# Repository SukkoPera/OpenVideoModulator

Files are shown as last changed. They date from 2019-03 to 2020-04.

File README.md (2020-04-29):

# OpenVideoModulator
OpenVideoModulator is an Open Hardware adapter that converts an RGB video signal to Composite and S-Video.

Board

## Summary
OpenVideoModulator is an Open Hardware implementation of [a small circuit found on the Amstrad CPC Wiki](http://www.cpcwiki.eu/index.php/RGB_SVideo) that is able to produce a composite video signal from separate red, green and blue color component signals (plus sync). Since it uses the AD724 encoder, it is also able to produce an S-Video (Y/C) signal and it supports both the PAL and NTSC standards.

It has a compact form factor, a low component count and it only requires a +5V power supply. This makes it useful with old computers that do not have a native composite or S-Video output, like the Amstrad CPC or the Commodore Amiga 500 (which actually has a composite output but it's only black & white). It also tries to maintain the smallest possible form factor, which might allow for an internal installation.

## Assembly and Usage
First of all you need to choose whether you want PAL or NTSC output. The board is preconfigured for PAL, if you need NTSC you will need to cut the link between pads 1-2 on the top of the board and solder 2-3 together. The crystal frequency also depends on your choice: use 4.433619 MHz for PAL or 3.579545 MHz for NTSC.

Solder the AD724 chip first, then all surface-mount components. Finally complete the board with the through-hole connectors and crystal.

One of C6 and C7 should be enough. I use a 100uF on C6 but that is probably overkill. Play with them if your output video signal is unstable.

The Composite/S-Video connector can be found from many Chinese sellers under the name *AV-MDC-401*. I chose this one as it was perfect for my needs, but the board should be easy to adapt to different connectors.

Usage should be straightforward: just provide power (make sure to match the polarity!) and video signals to the board, then get your output from the other side. Note that the *sync* input requires a *composite sync* signal.

## License
The OpenVideoModulator documentation, including the design itself, is copyright &copy; SukkoPera 2019-2020.

OpenVideoModulator is Open Hardware licensed under the [CERN OHL v. 1.2](http://ohwr.org/cernohl).

You may redistribute and modify this documentation under the terms of the CERN OHL v.1.2. This documentation is distributed *as is* and WITHOUT ANY EXPRESS OR IMPLIED WARRANTIES whatsoever with respect to its functionality, operability or use, including, without limitation, any implied warranties OF MERCHANTABILITY, SATISFACTORY QUALITY, FITNESS FOR A PARTICULAR PURPOSE or infringement. We expressly disclaim any liability whatsoever for any direct, indirect, consequential, incidental or special damages, including, without limitation, lost revenues, lost profits, losses resulting from business interruption or loss of data, regardless of the form of action or legal theory under which the liability may be asserted, even if advised of the possibility or likelihood of such damages.

A copy of the full license is included in file [LICENSE.pdf](LICENSE.pdf), please refer to it for applicable conditions. In order to properly deal with its terms, please see file [LICENSE_HOWTO.pdf](LICENSE_HOWTO.pdf).

The contact points for information about manufactured Products (see section 4.2) are listed in file [PRODUCT.md](PRODUCT.md).

Any modifications made by Licensees (see section 3.4.b) shall be recorded in file [CHANGES.md](CHANGES.md).

The Documentation Location of the original project is https://github.com/SukkoPera/OpenVideoModulator/.

## Support the Project
Since the project is open you are free to get the PCBs made by your preferred manufacturer, however in case you want to support the development, you can order them from PCBWay through this link:

PCB from PCBWay (https://www.pcbway.com/project/shareproject/OpenVideoModulator_V1.html)

You get my gratitude and cheap, professionally-made and good quality PCBs, I get some credit that will help with this and [other projects](https://www.pcbway.com/project/member/shareproject/?bmbid=41100). You won't even have to worry about the various PCB options, it's all pre-configured for you!

Also, if you still have to register to that site, [you can use this link](https://www.pcbway.com/setinvite.aspx?inviteid=41100) to get some bonus initial credit (and yield me some more).

Again, if you want to use another manufacturer, feel free to, don't feel obligated :). But then you can buy me a coffee if you want:

<a href='https://ko-fi.com/L3L0U18L' target='_blank'>Buy Me a Coffee at ko-fi.com</a>

## Get Help
If you need help or have questions, you can join [the official Telegram group](https://t.me/joinchat/HUHdWBC9J9JnYIrvTYfZmg).

## Thanks
- CPC Wiki for the original circuit.

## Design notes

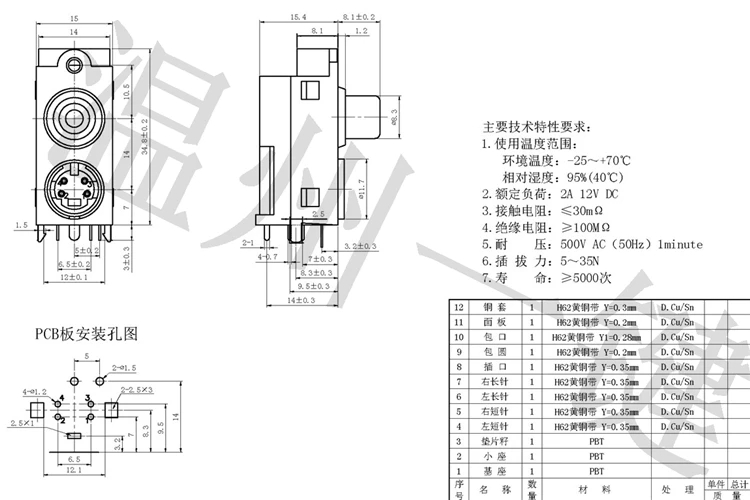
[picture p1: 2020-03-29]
doc/AV-MDC-401.jpg

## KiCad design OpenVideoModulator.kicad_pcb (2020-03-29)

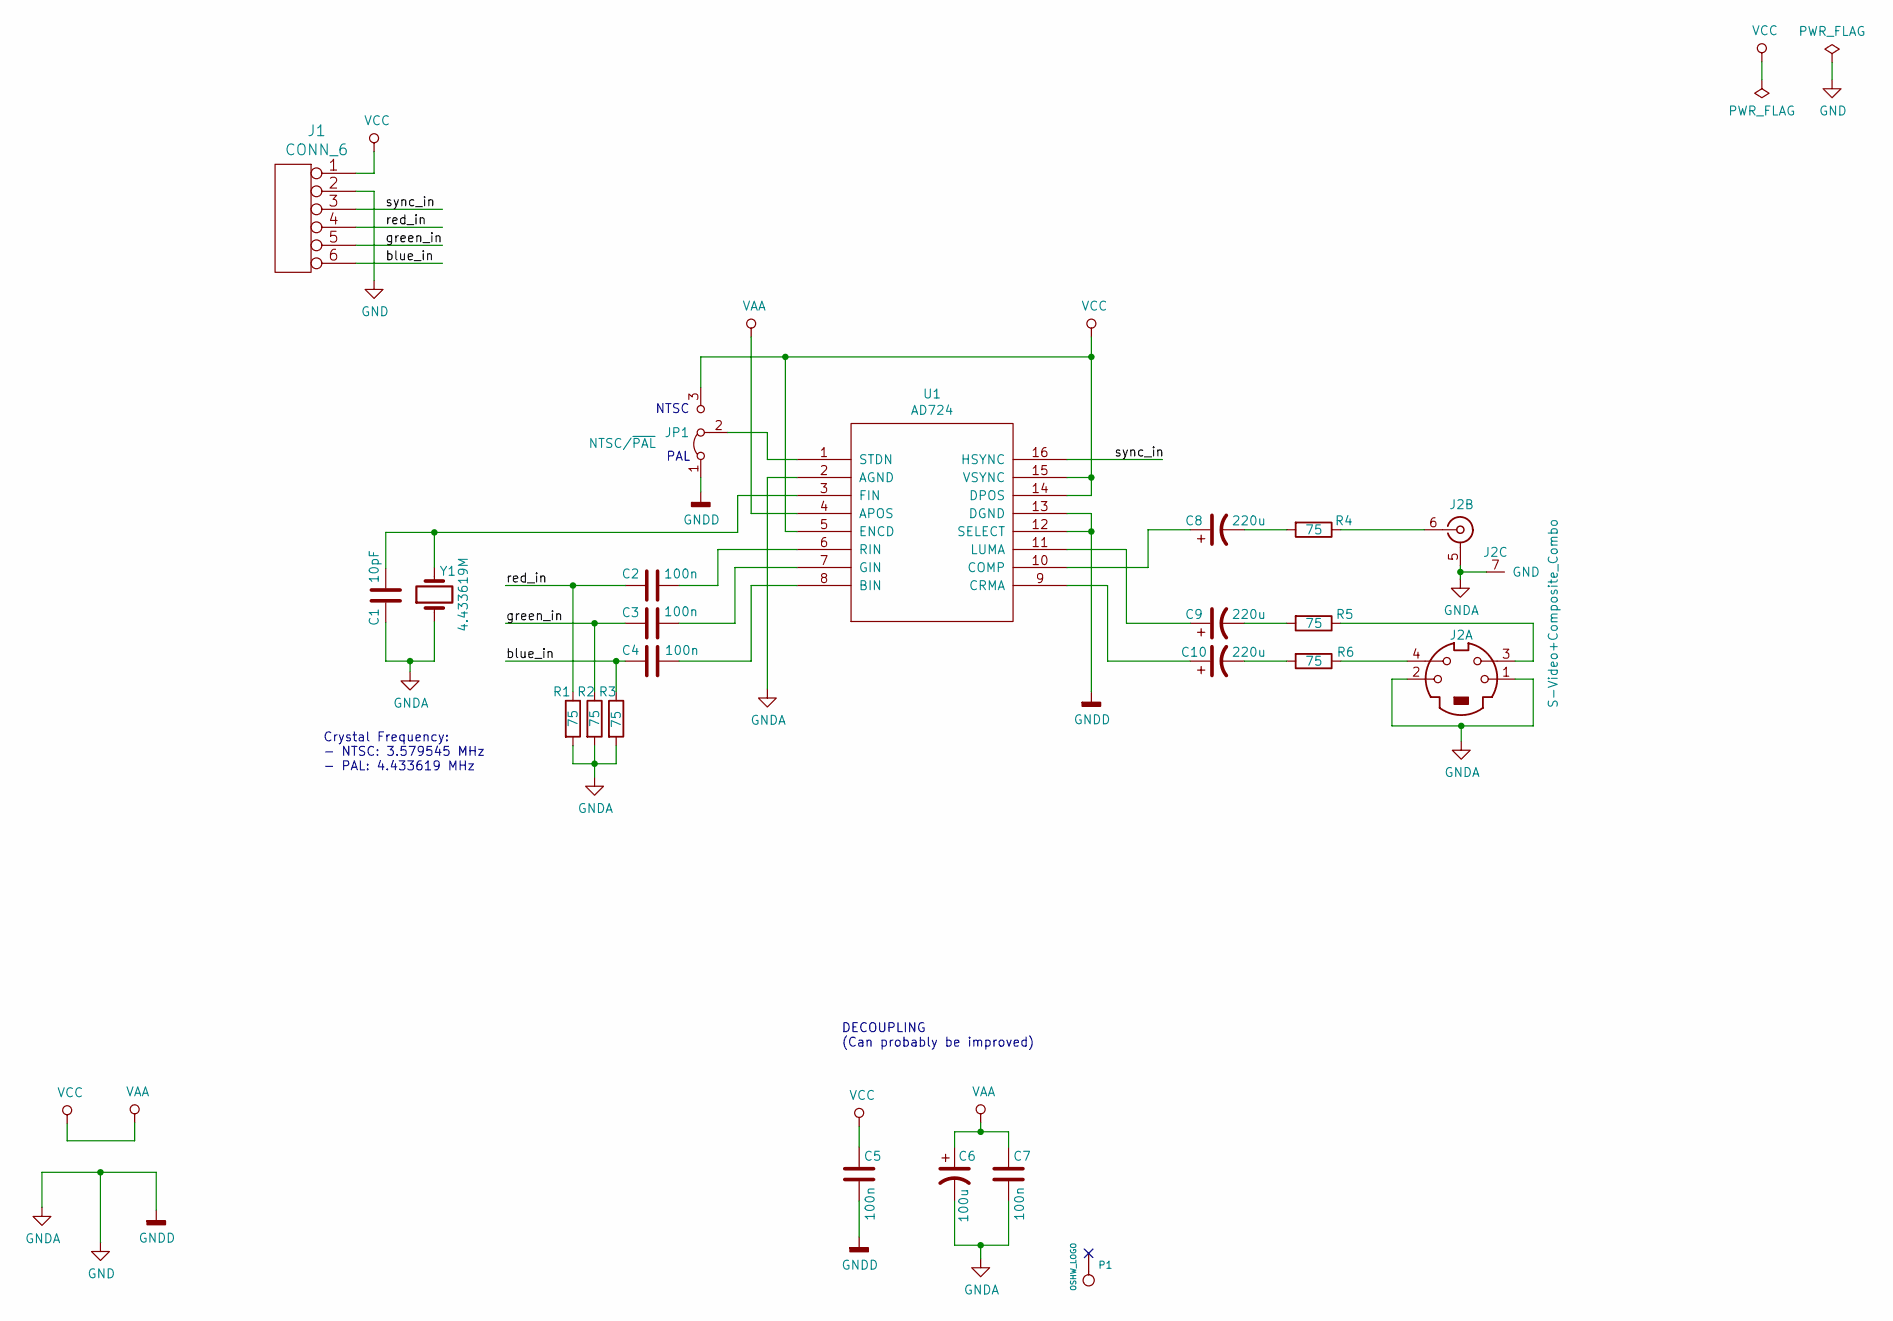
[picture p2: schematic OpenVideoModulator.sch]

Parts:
C1: 10pF; C_0805_2012Metric_Pad1.15x1.40mm_HandSolder
C2, C3, C4, C5: 100n; C_0805_2012Metric_Pad1.15x1.40mm_HandSolder
C6: 100u; CP_Elec_6.3x5.8
C7: 100n; C_1206_3216Metric_Pad1.42x1.75mm_HandSolder
C8, C9, C10: 220u; CP_Radial_D6.3mm_P2.50mm
J1: CONN_6; PinHeader_1x06_P2.54mm_Vertical
J2: S-Video+Composite_Combo; AV-MDC-401
JP1: NTSC/~PAL; SolderJumper-3_P1.3mm_Bridged12_RoundedPad1.0x1.5mm
P1: OSHW_LOGO; OSHW-Logo2_7.3x6mm_Copper
R1, R2, R3, R4, R5, R6: 75; R_0805_2012Metric_Pad1.15x1.40mm_HandSolder
U1: AD724; SOIC-16W_7.5x10.3mm_P1.27mm
Y1: 4.433619M; Crystal_HC49-4H_Vertical

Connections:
/blue_in: C4.2, J1.6, R3.1
/green_in: C3.2, J1.5, R2.1
/red_in: C2.2, J1.4, R1.1
/sync_in: J1.3, U1.16 (HSYNC)
GND: C1.2, C5.1, C6.2, C7.1, J1.2, J2.1, J2.2, J2.5, J2.7 (GND), JP1.1 (A), R1.2, R2.2, R3.2, U1.2 (AGND), U1.12 (SELECT), U1.13 (DGND), Y1.1
unnamed: C1.1, U1.3 (FIN), Y1.2
unnamed: C2.1, U1.6 (RIN)
unnamed: C3.1, U1.7 (GIN)
unnamed: C4.1, U1.8 (BIN)
unnamed: C8.1, U1.10 (COMP)
unnamed: C8.2, R4.2
unnamed: C9.1, U1.11 (LUMA)
unnamed: C9.2, R5.2
unnamed: C10.1, U1.9 (CRMA)
unnamed: C10.2, R6.2
unnamed: J2.3, R5.1
unnamed: J2.4, R6.1
unnamed: J2.6, R4.1
unnamed: JP1.2 (C), U1.1 (STDN)
VAA: C5.2, C6.1, C7.2, J1.1, JP1.3 (B), U1.4 (APOS), U1.5 (ENCD), U1.14 (DPOS), U1.15 (VSYNC)

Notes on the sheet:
PAL
NTSC
Crystal Frequency: - NTSC: 3.579545 MHz - PAL: 4.433619 MHz
DECOUPLING (Can probably be improved)

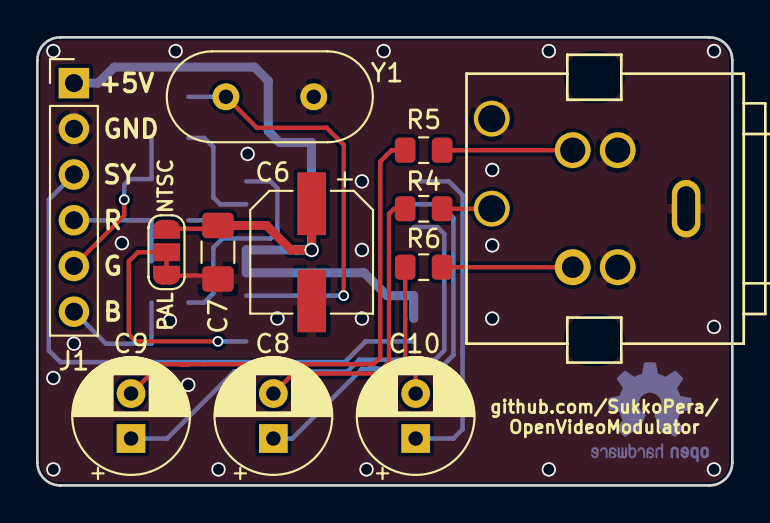
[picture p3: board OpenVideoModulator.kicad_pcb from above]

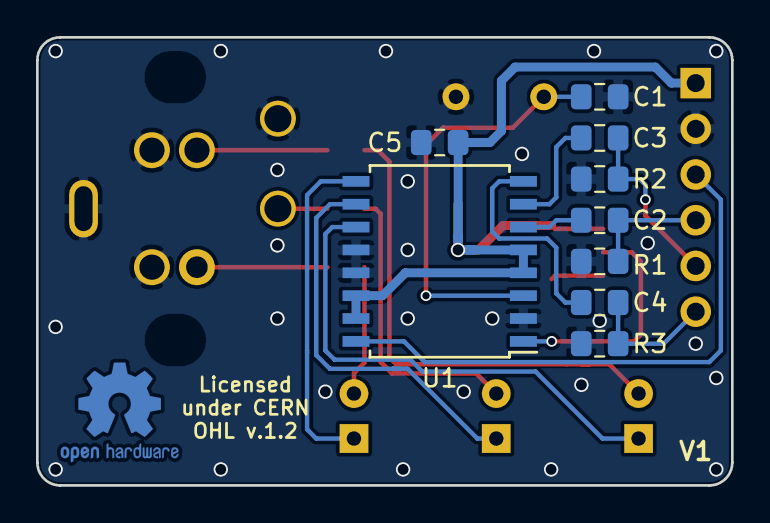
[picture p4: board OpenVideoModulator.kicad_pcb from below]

Board: 2 copper layers, 38.6 x 24.9 mm, 22 parts (10 on the bottom side), 20 nets.

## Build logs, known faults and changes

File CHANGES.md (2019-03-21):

## CHANGES

Any modifications to the OpenVideoModulator design and documentation made by any Licensee MUST be noted in this file, as per *section 3.4.b* of the [license](LICENSE.pdf).

### (Date) - (Author)
(Description)

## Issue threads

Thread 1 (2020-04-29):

Pal Crystal correct frequency.

amazzanti, 2020-04-29:
Hi,

here to remind you the Pal Crystal frequency is 4.433619MHZ.

Thanks,

Antonio

snnsyhn, 2020-04-29:
Hello Antonio
My name is Sinan
I want to use your “OpenC64KernalCart V1” in my project if you let me.
https://www.pcbway.com/project/shareproject/OpenC64KernalCart_V1.html
My regads
Sinan
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

Closed 2020-04-29.

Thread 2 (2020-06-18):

No GND on C8,C9,C10

ojaksch, 2020-06-18:
I've ordered a set of five from pcbway for my own projects. As U1 and J2 are still in delivery I already soldered all other parts.
While waiting for the U1's and J2's I've checked the pcb's for continuity but I'm missing GND at all elco's/cathode. GND **is** available at the small holes beside the elco's but not at any cathode of C8,C9 and C10.
Is this an issue by you or maybe by pcbway?

SukkoPera, 2020-06-18:
Those points are NOT connected to ground. Look at the schematics and you'll understand ;).

ojaksch, 2020-06-18:
Ah, yes, I see. I think I was trapped by the doublelayered and doublesided pcb with encrypted gerbers - and haven't realized the presence of the kicad file. All is good. Sorry for making any noise :)
Thanks for sharing this project! I'm curious for the video output of my CPC464...

Closed 2020-06-18.

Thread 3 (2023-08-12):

Please add the complete BOM

arm1969, 2023-08-12:
I couldn't find the exact bill of materials .. please add this. thanks

SukkoPera, 2023-08-12:
It's right there, in the release page.

Closed 2023-08-12.

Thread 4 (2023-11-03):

the image that comes out is black and white, distorted and jumpy.

Cyrus331, 2023-11-03:
Hello, I grafted this module to the RGB output terminal of PCENGINE. The crystal oscillator has been changed to NTSC and the jumper has been connected to NTSC, but the image that comes out is black and white, distorted and jumpy. I don’t know what the problem is.

It is normal for RGB signals to be output to the TV
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

SukkoPera, 2023-11-03:
It's very hard to say. First of all it seems that you have redesigned the board in a different software package and you could have made errors in that. Please double check that the schematics match perfectly.

Apart from that, if you have bought your AD724 chips from China, they might be bad, I know that are batches around that do not let the crystal start to oscillate properly (or maybe they need a particular crystal, I really don't know, sometimes just touching the crystal makes it work correctly.

I don't know what else to suggest, I guarantee that my original board works correctly and I know that other people have derived working designs from it.

Closed 2023-11-03.

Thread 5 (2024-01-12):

Doesn't appear to work with NTSC?

GK6475, 2024-01-12:
Hi, so I soldered everything onto the board appropriately with NTSC configuration, but the signal coming out is very messy. The luma and sync show up to some extent, but the chroma is very unstable and flashes constantly. I've tried using RGB from a Sega Genesis, which I know works normally, and also from my computer with CRT emudriver. Both produced the same results. How can I fix this issue?

Video of issue:
https://drive.google.com/file/d/1a7pYuHD8HxAwpXQZXlm3o_29vsbsfbSq/view?usp=sharing

SukkoPera, 2024-01-12:
Since I live in Europe, I have never used the NTSC configuration, but I think others did with success.

Some random hints:
- Make sure the crystal is the right frequency: you need 3.579545 MHz for NTSC.
- Different crystals might need different values of C1: generally something between 12 and 22 pF works but you should really check the datasheet for your crystal.
- Make sure to use at least 10 uF at C10, 100 uF is better.
- Finally, I think there's a bad batch of AD724 chips around, if you bought it from China: I have had similar issues with the last few I bought, but chips from an earlier purchase worked fine. I don't know if they have a manufacturing fault, require a different crystal or whatever, but they only work well if I physically TOUCH che crystal while the machine is on. This suggests an issue with C1 but I haven't been able to get them to work reliably yet.

Good luck!

GK6475, 2024-01-12:
This is the datasheet for my crystal:
https://www.mouser.com/datasheet/2/3/ab-1499141.pdf

Seems like 10 pF should work to some extent. Any advice?

SukkoPera, 2024-01-15:
You might actually want to try higher values, as high as 32 pF.

I know original AD724s are not cheap but well, there might be a reason for that ;). I can't really recommend any, I've been lucky enough to find a Chinese batch that is working and I have just used those so far.

GK6475, 2024-01-16:
Ah, well I tried 20pF, but that didn't change much. Guess I'll have to find a better source of AD724s.

GK6475, 2025-04-27:
Came back to this over a year later, and it was just my sync signal the whole time. Apparently the AD724 doesn't like 75 ohm CSYNC, and prefers TTL (LM1881 works great with it). Heh, I guess now I can make 10-20 of these since I bought a few different packs of chips.

Closed 2024-01-12.

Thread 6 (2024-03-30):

Schematics for the overall circuit

kattan1969, 2024-03-30:
Would you please provide the schematics for the circuit? I checked the "docs" folder and couldn't find any!
Many thanks

SukkoPera, 2024-03-30:
That will take some time. Maybe you can just install Kicad and open the project?

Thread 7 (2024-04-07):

PAL with color bleed; unclear

kattan1969, 2024-04-07:
I tested the board with both C6 and C7 capacitors soldered and ended up with a jumpy and flakey image. So, as you have suggested I decided to "play with them". Removing C7 first resulted a very bad and unstable video signal. Putting C7 back and removing C6 resulted a kind-of stable image but with terrible color bleed. Now I'm sure the chips/components I'm using is good. Could be the video chip is a Chinese one (though I purchased from the States!!)
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

SukkoPera, 2024-04-08:
I'm assuming you are using the correct PAL frequency crystal and that the jumper is set to PAL.

I'd just use 100uF for C6 and 100nF for C7.

SukkoPera, 2024-04-08:
Well, I don't know what to say, it works very well for me. Check the soldering.

Maybe you can try to analyze the other circuit and see what's different? It looks very similar at first glance.

kattan1969, 2024-04-08:
OK, I ordered a new set of AD724JRZ chips from reputable seller based in the States. My previous set of chips (AD724JR) look different and there is a possibility that they are not genuine. Once the new chips arrive I will assemble a new PCB (as I have 10 of these) and report back the results.
I really need this circuit as it's more convenient to plug My Amiga 500 into any TV. Yet, with a very nostalgic display (yes, I know HDMI and VGA look better but having composite video out is part of the fun)

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

kattan1969, 2024-05-18:
It seems, at least for me, that this project is a bummer! Based on my previous comments (above), I presumed that may be the chips I purchased were fake. So I ordered new set of chips for a reputable seller and assembled a new circuit using a new PCB to get the result shown in the photo. The old and the new set of chips are also shown.
I think this circuit is probably suitable for certain TVs with special PAL versions. I have tested this on the TVs I have at home (3 of them) and the picture is more or less the same!!!

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

SukkoPera, 2024-05-23:
The problem might be in the crystal then. Try touching it :).

(Not joking.)

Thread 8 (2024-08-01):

List of components

sageofeon, 2024-08-01:
Could you please provide a list of components and their values?

SukkoPera, 2024-08-01:
BOM is under the Release page.

Closed 2024-08-01.

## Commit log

2019-03-20 Almost there...
    [OpenVideoModulator.kicad_pcb, OpenVideoModulator.sch]
2019-03-20 Add missing footprint
2019-03-21 Minor fixes
    [OpenVideoModulator.kicad_pcb]
2019-03-21 More fixes
    [OpenVideoModulator.kicad_pcb]
2019-03-21 Use 6.3mm electrolytics, as 220uF seem to be more common this size At least >= 16V models, which are recommended
    [OpenVideoModulator.kicad_pcb, OpenVideoModulator.sch]
2019-03-21 Stitch grounds
    [OpenVideoModulator.kicad_pcb]
2019-03-21 Ground S-Video connector shielding... AND READY FOR V1!
    [OpenVideoModulator.kicad_pcb, OpenVideoModulator.sch]
2020-03-29 Final touches for release
    [OpenVideoModulator.kicad_pcb, OpenVideoModulator.sch]

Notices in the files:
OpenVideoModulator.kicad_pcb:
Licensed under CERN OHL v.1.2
